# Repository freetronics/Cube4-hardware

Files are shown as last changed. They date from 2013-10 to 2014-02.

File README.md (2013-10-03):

Freetronics Cube
===========================
Copyright 2010-2013 Freetronics Pty Ltd  
Freetronics site:  www.freetronics.com  
Freetronics email: info@freetronics.com  

The Cube is a USB powered, smart RGB LED Cube kit, with a serial command
interface for direct control and learning, an open source driver library
and an on-board Arduino compatible MCU running the whole show!

The Cube was designed using the open source KiCad schematic and pcb
design package: http://www.kicad-pcb.org

The schematic pages have been carefully laid out to make it easy to follow and
learn about a larger microcontroller based project design in operation.

Features:

 * Power and control by USB commands straight from your computer (Windows, Mac or Linux)
 * Expansion port connector for sensors, joysticks, game and interface add ons
 * Onboard ATmega32u4 MCU (Arduino Leonardo compatible)
 * USB interface for uploading new sketches and sending serial commands
 * Arduino driver library with example programs and animations at:
   https://github.com/freetronics/Cube4
 * Includes ZigBee/XBee headers so you can add a wireless module (not included)
 * Prototyping area with I2C, power and spare pins next to it

More information is available on our product page at:

  http://www.freetronics.com/cube

This project is made up of 3 schematic and pcb project folders.
Each folder within this repository includes a handy copy of the
schematic in PDF format and image(s) of the main pcb.

INSTALLATION
------------
The design is saved as a KiCad project. KiCad PCB design software is
available from www.kicad-pcb.org free and open-source. To use
this project download it and place the directories containing these files
into the a folder on your computer. Then open KiCad and navigate to the
*.pro (project) file for each section.

DISTRIBUTION
------------
The specific terms of distribution of this project are governed by the
license referenced below.

LICENSE
-------
Licensed under the TAPR Open Hardware License (www.tapr.org/OHL).
The "license" folder within this repository also contains a copy of
this license in plain text format.

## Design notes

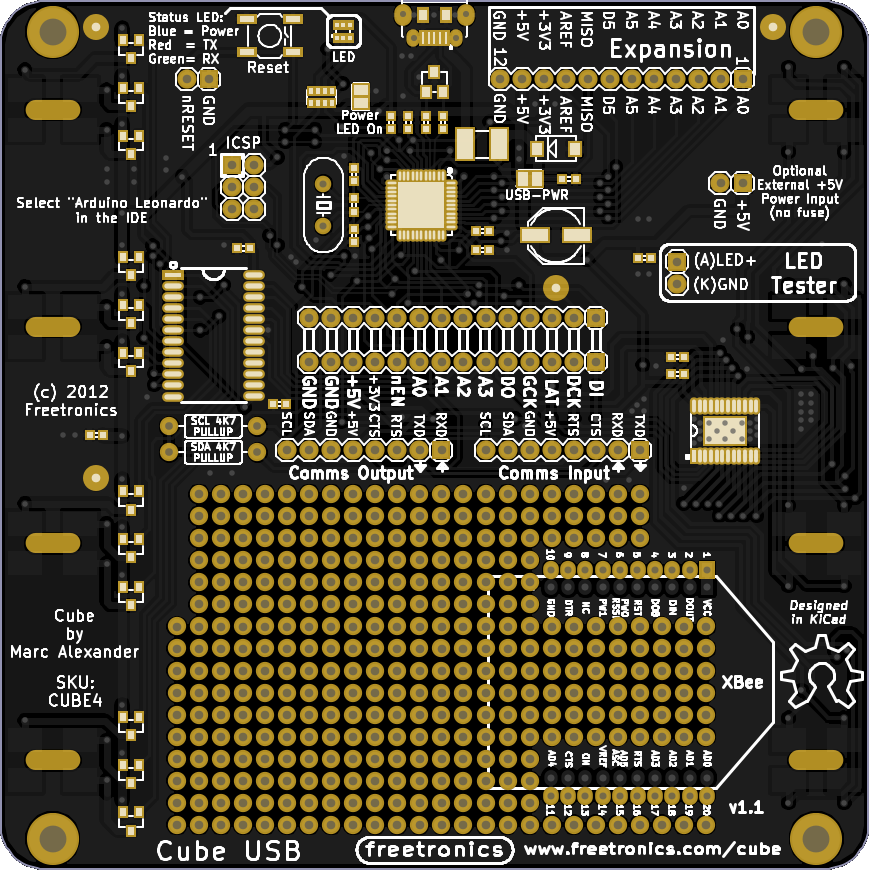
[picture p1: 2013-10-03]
cube4/cube4-top-black.png

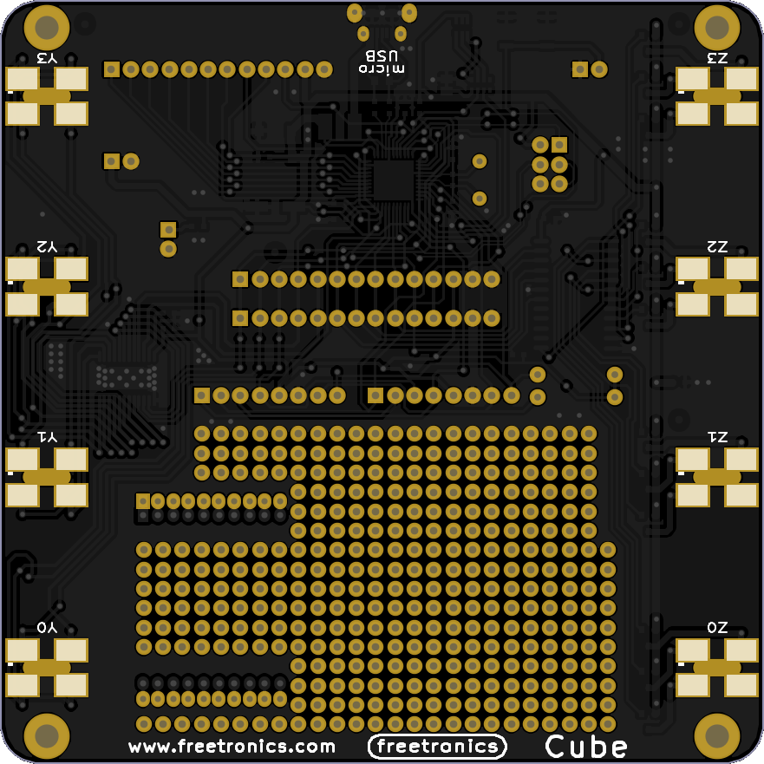
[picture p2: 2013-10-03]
cube4/cube4-bottom-black.png

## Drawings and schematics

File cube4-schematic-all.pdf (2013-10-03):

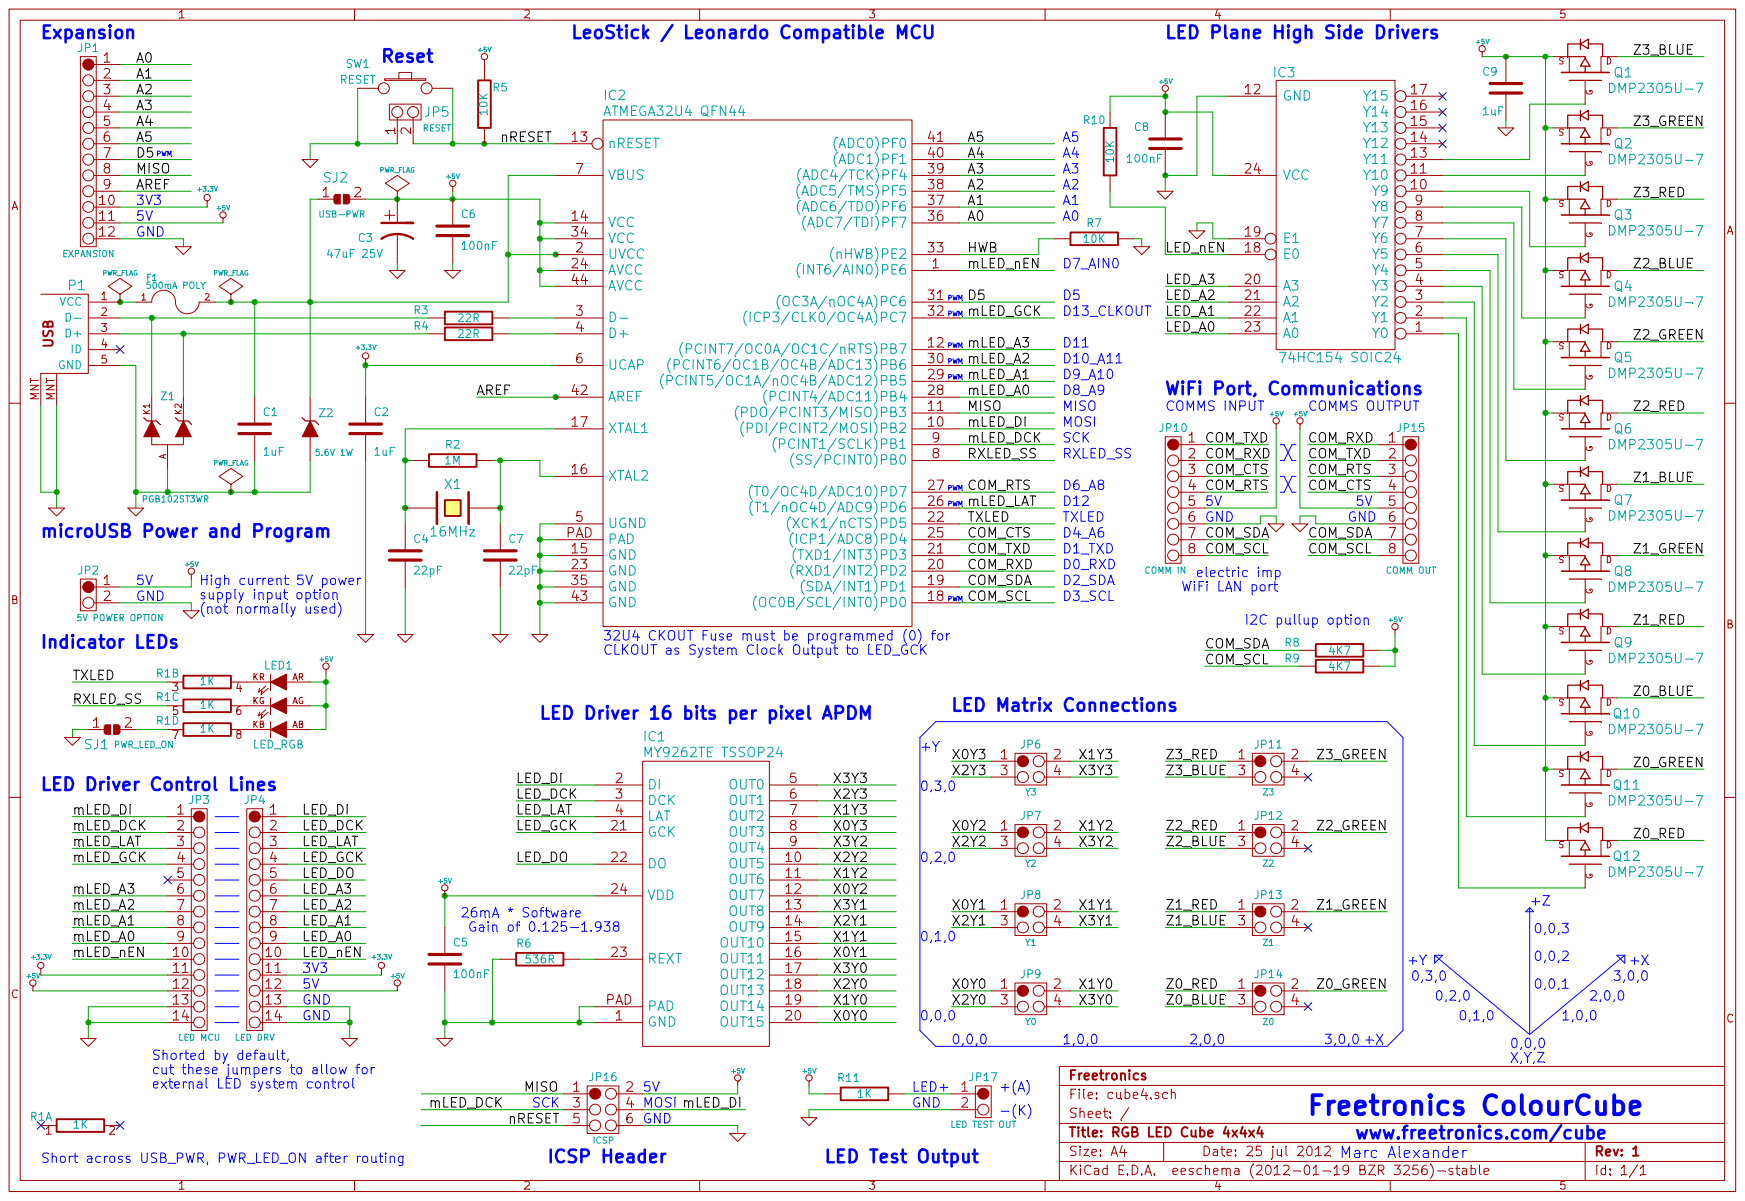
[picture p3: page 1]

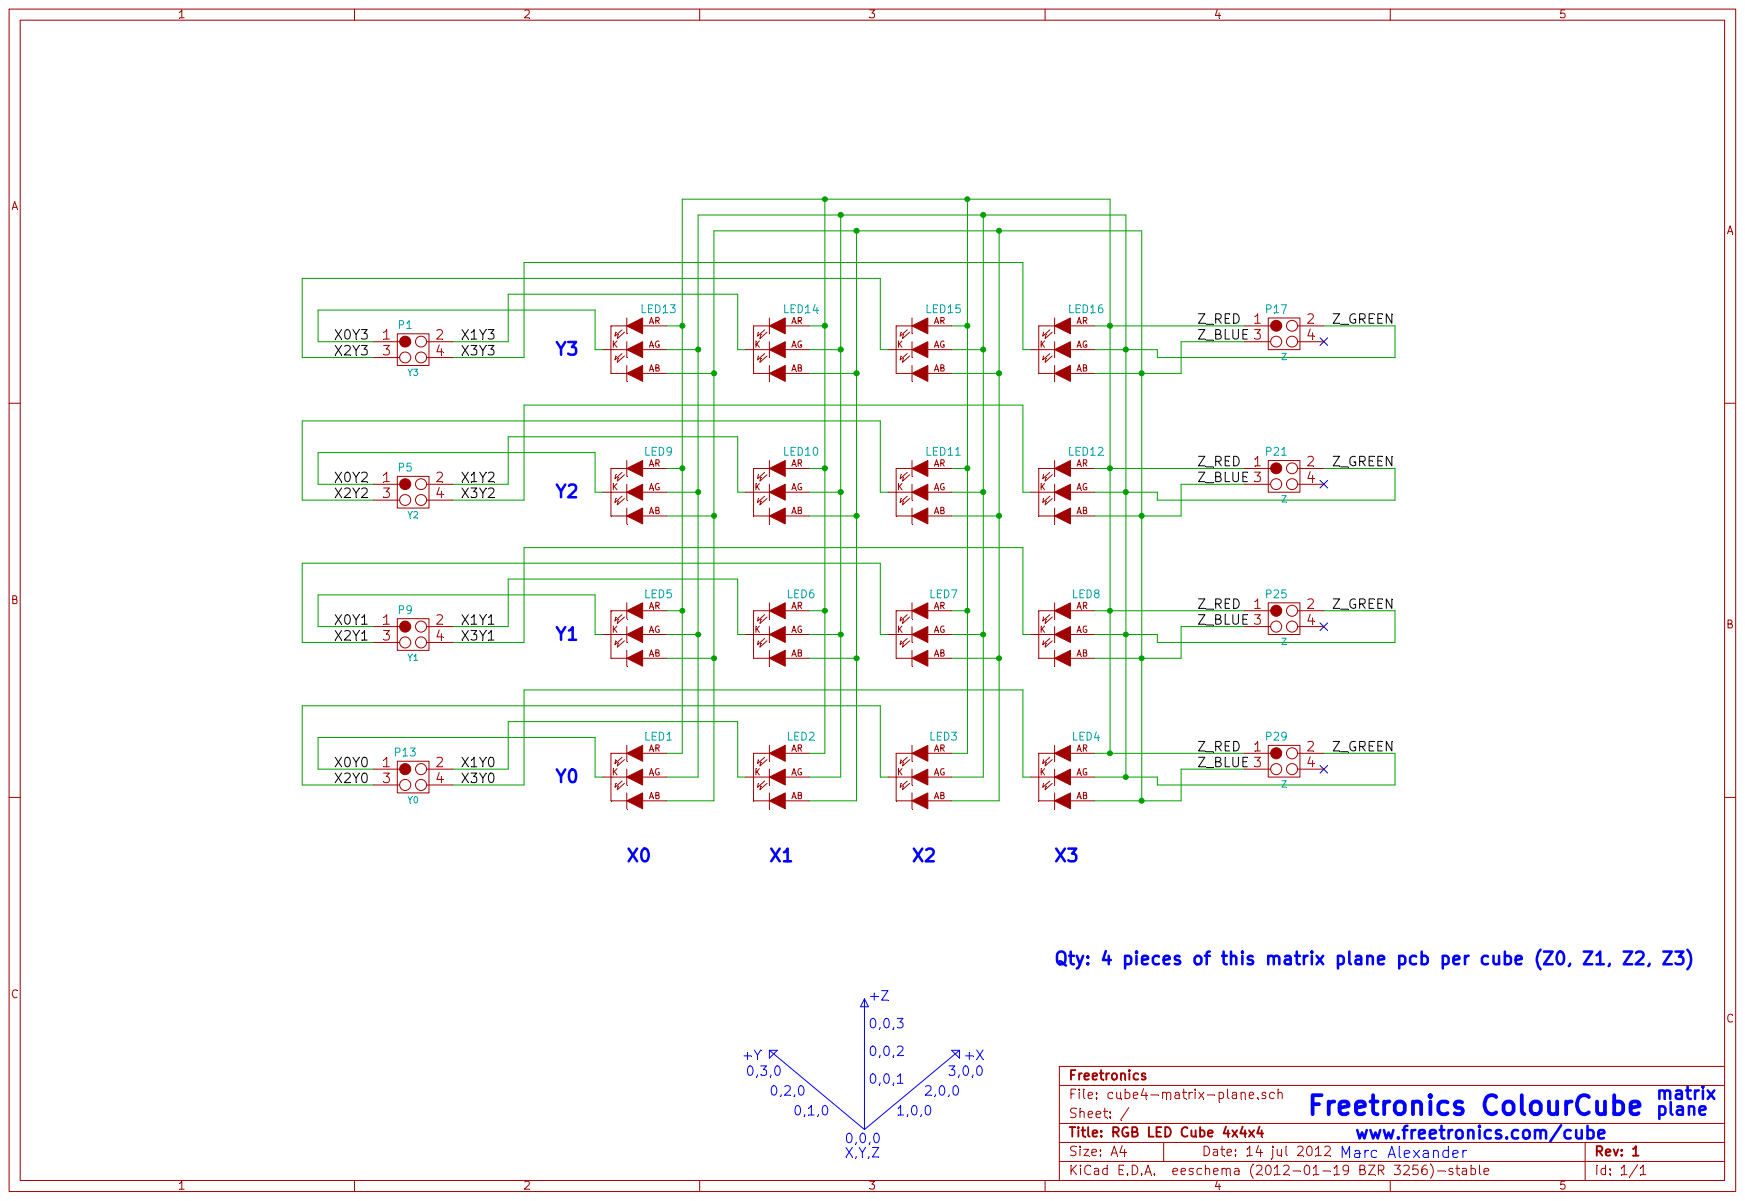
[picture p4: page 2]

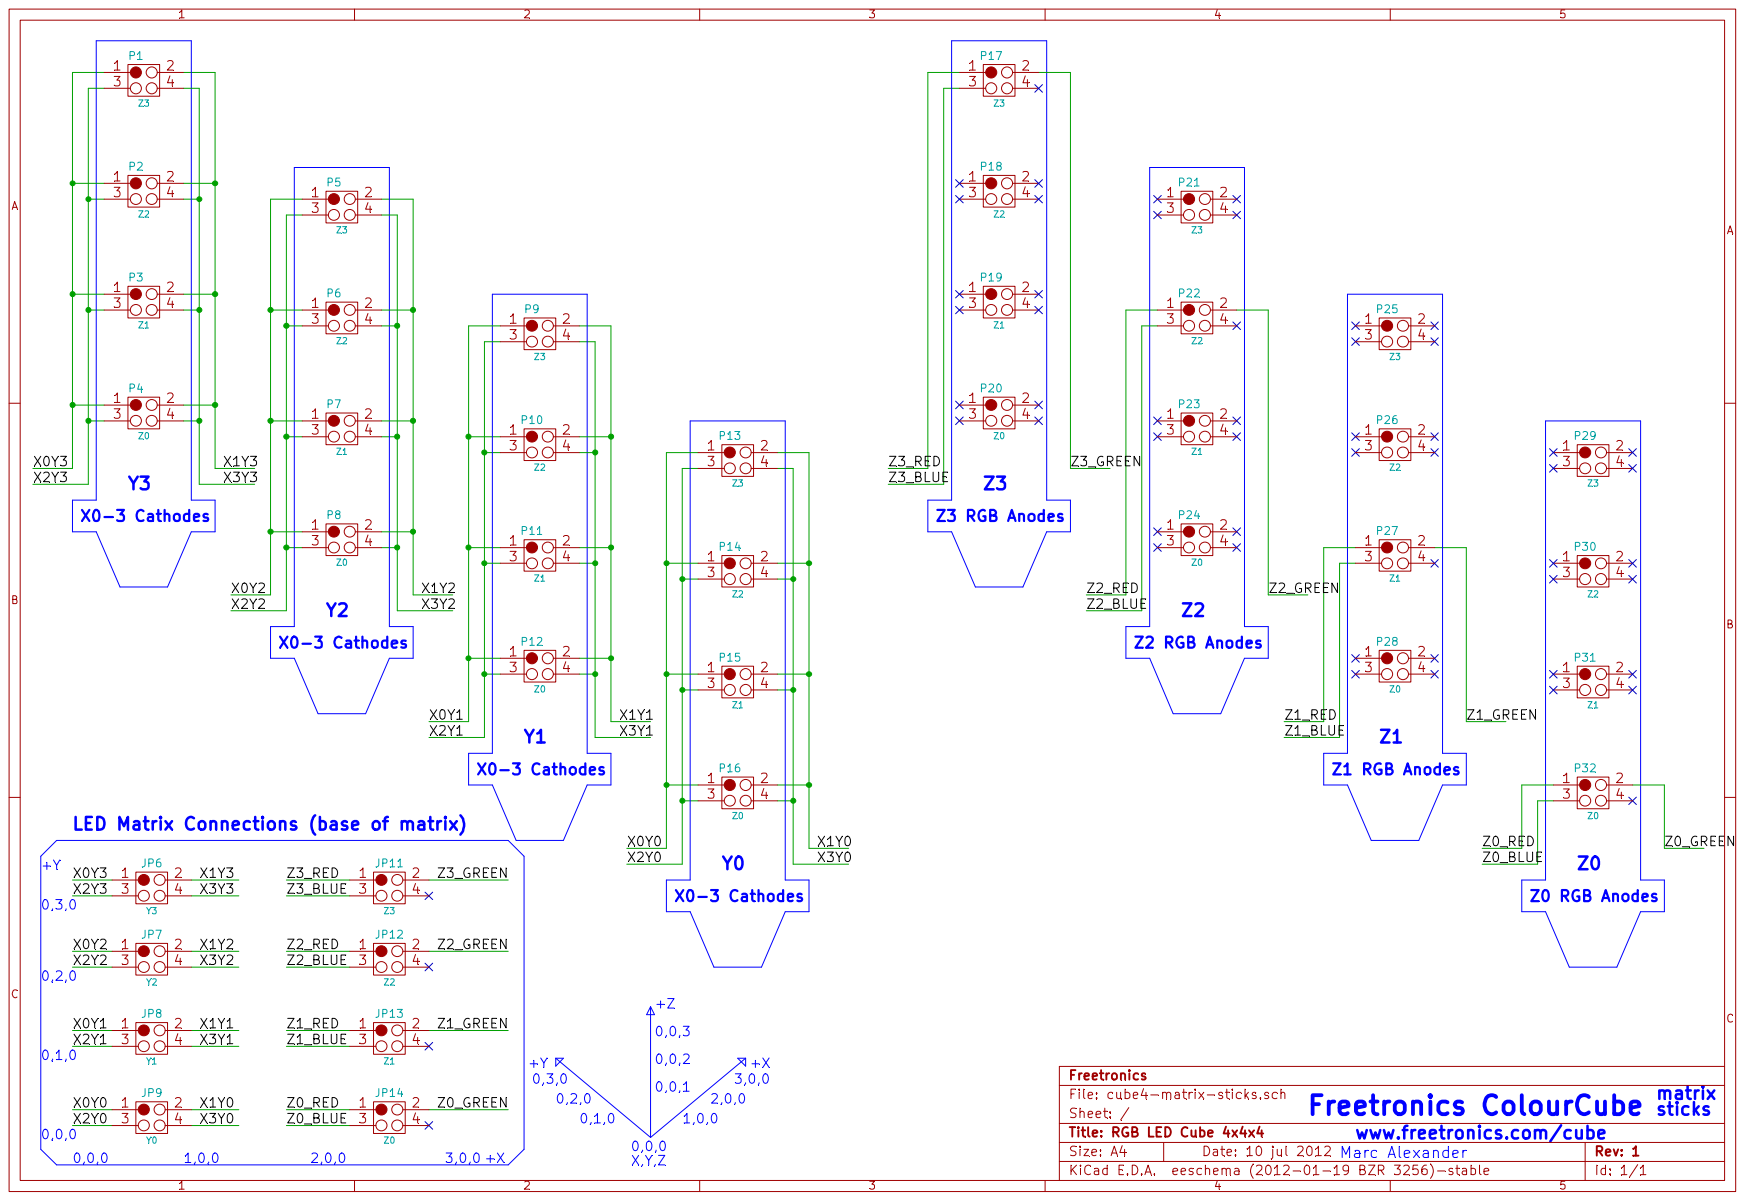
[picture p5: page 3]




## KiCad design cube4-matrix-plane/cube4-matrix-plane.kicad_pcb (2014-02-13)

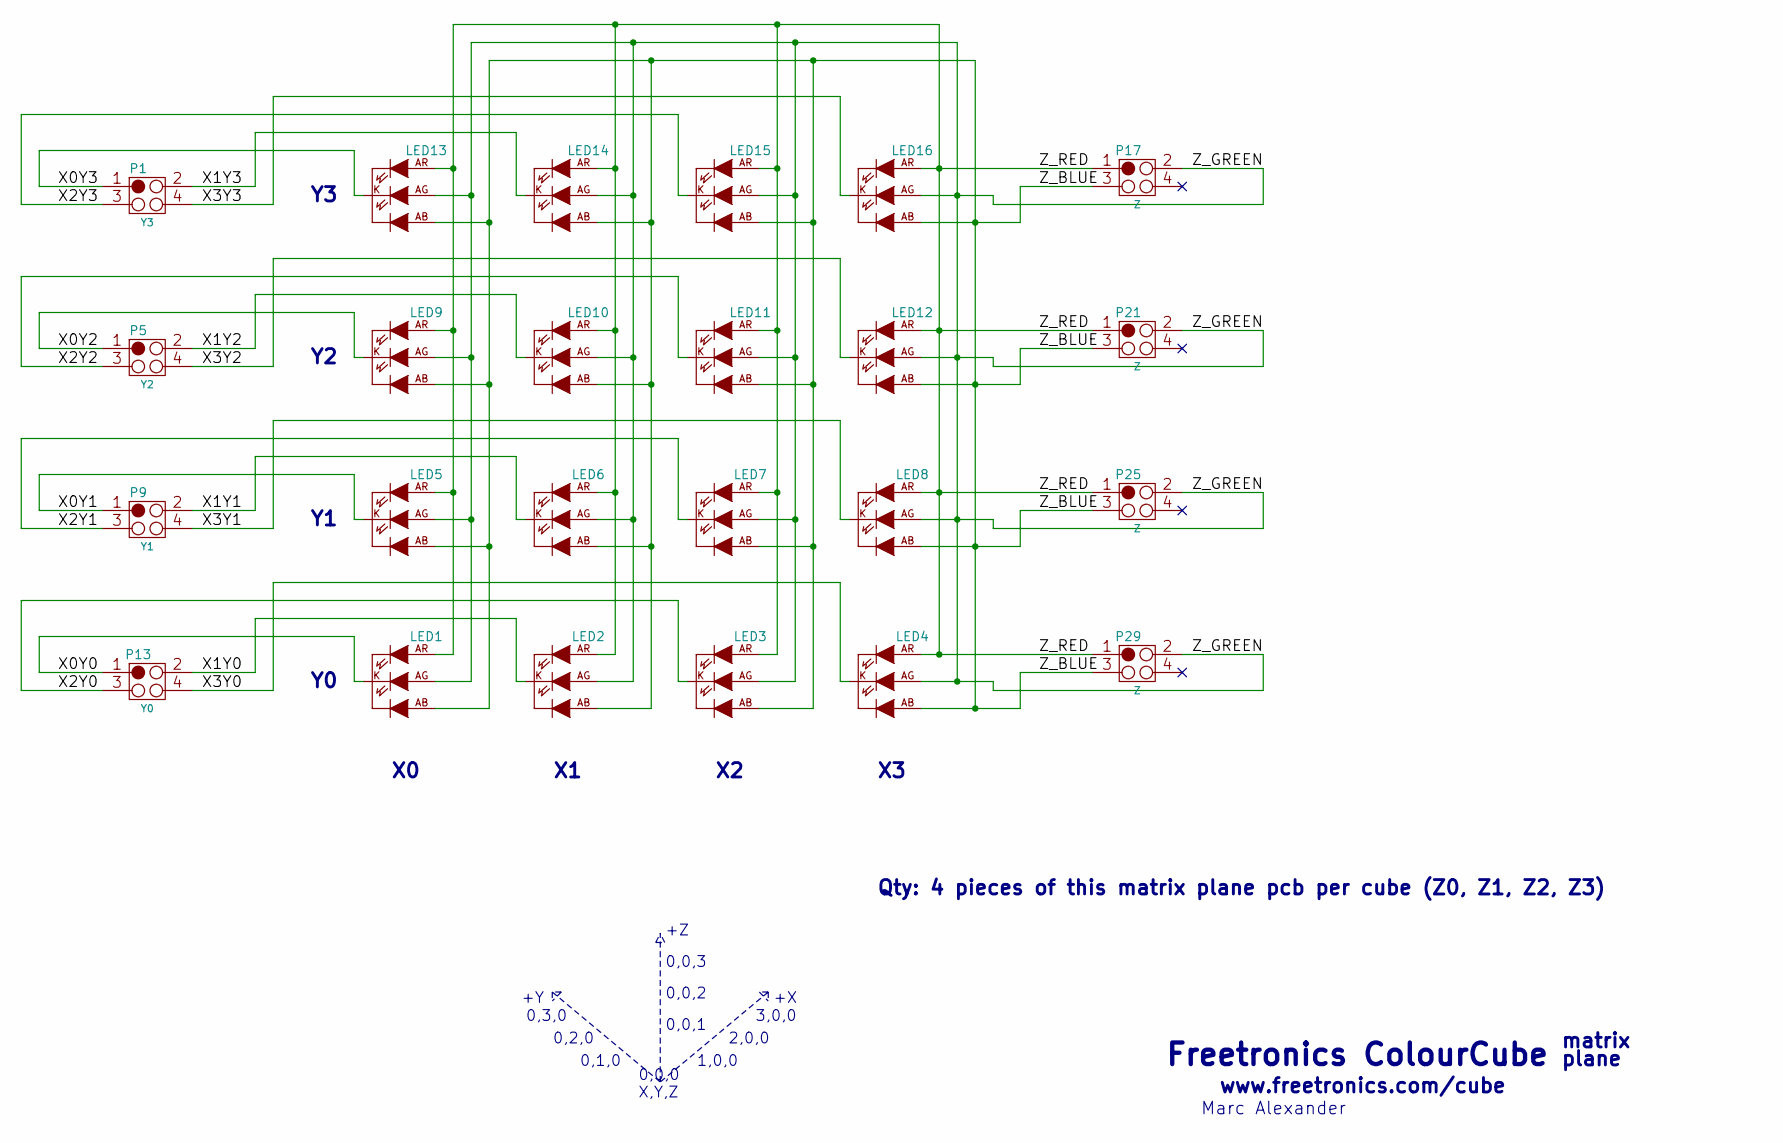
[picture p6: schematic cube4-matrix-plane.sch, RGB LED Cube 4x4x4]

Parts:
LED1, LED2, LED3, LED4, LED5, LED6, LED7, LED8, LED9, LED10, LED11, LED12, LED13, LED14, LED15, LED16: LED_RGB_COM_K; LED_RGB_8MM_COM_K
P1: Y3; LED_MATRIX_PLANE_4PAD
P5: Y2; LED_MATRIX_PLANE_4PAD
P9: Y1; LED_MATRIX_PLANE_4PAD
P13: Y0; LED_MATRIX_PLANE_4PAD
P17, P21, P25, P29: Z; LED_MATRIX_PLANE_4PAD

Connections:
/X0Y0: LED1.K, P13.1
/X0Y1: LED5.K, P9.1
/X0Y2: LED9.K, P5.1
/X0Y3: LED13.K, P1.1
/X1Y0: LED2.K, P13.2
/X1Y1: LED6.K, P9.2
/X1Y2: LED10.K, P5.2
/X1Y3: LED14.K, P1.2
/X2Y0: LED3.K, P13.3
/X2Y1: LED7.K, P9.3
/X2Y2: LED11.K, P5.3
/X2Y3: LED15.K, P1.3
/X3Y0: LED4.K, P13.4
/X3Y1: LED8.K, P9.4
/X3Y2: LED12.K, P5.4
/X3Y3: LED16.K, P1.4
/Z_BLUE: LED1.AB, LED2.AB, LED3.AB, LED4.AB, LED5.AB, LED6.AB, LED7.AB, LED8.AB, LED9.AB, LED10.AB, LED11.AB, LED12.AB, LED13.AB, LED14.AB, LED15.AB, LED16.AB, P17.3, P21.3, P25.3, P29.3
/Z_GREEN: LED1.AG, LED2.AG, LED3.AG, LED4.AG, LED5.AG, LED6.AG, LED7.AG, LED8.AG, LED9.AG, LED10.AG, LED11.AG, LED12.AG, LED13.AG, LED14.AG, LED15.AG, LED16.AG, P17.2, P21.2, P25.2, P29.2
/Z_RED: LED1.AR, LED2.AR, LED3.AR, LED4.AR, LED5.AR, LED6.AR, LED7.AR, LED8.AR, LED9.AR, LED10.AR, LED11.AR, LED12.AR, LED13.AR, LED14.AR, LED15.AR, LED16.AR, P17.1, P21.1, P25.1, P29.1

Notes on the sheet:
Qty: 4 pieces of this matrix plane pcb per cube (Z0, Z1, Z2, Z3)
plane
matrix
Marc Alexander
www.freetronics.com/cube
Freetronics ColourCube
0,0,3
0,0,2
0,0,1
0,3,0
0,2,0
0,1,0
3,0,0
2,0,0
1,0,0
0,0,0 X,Y,Z

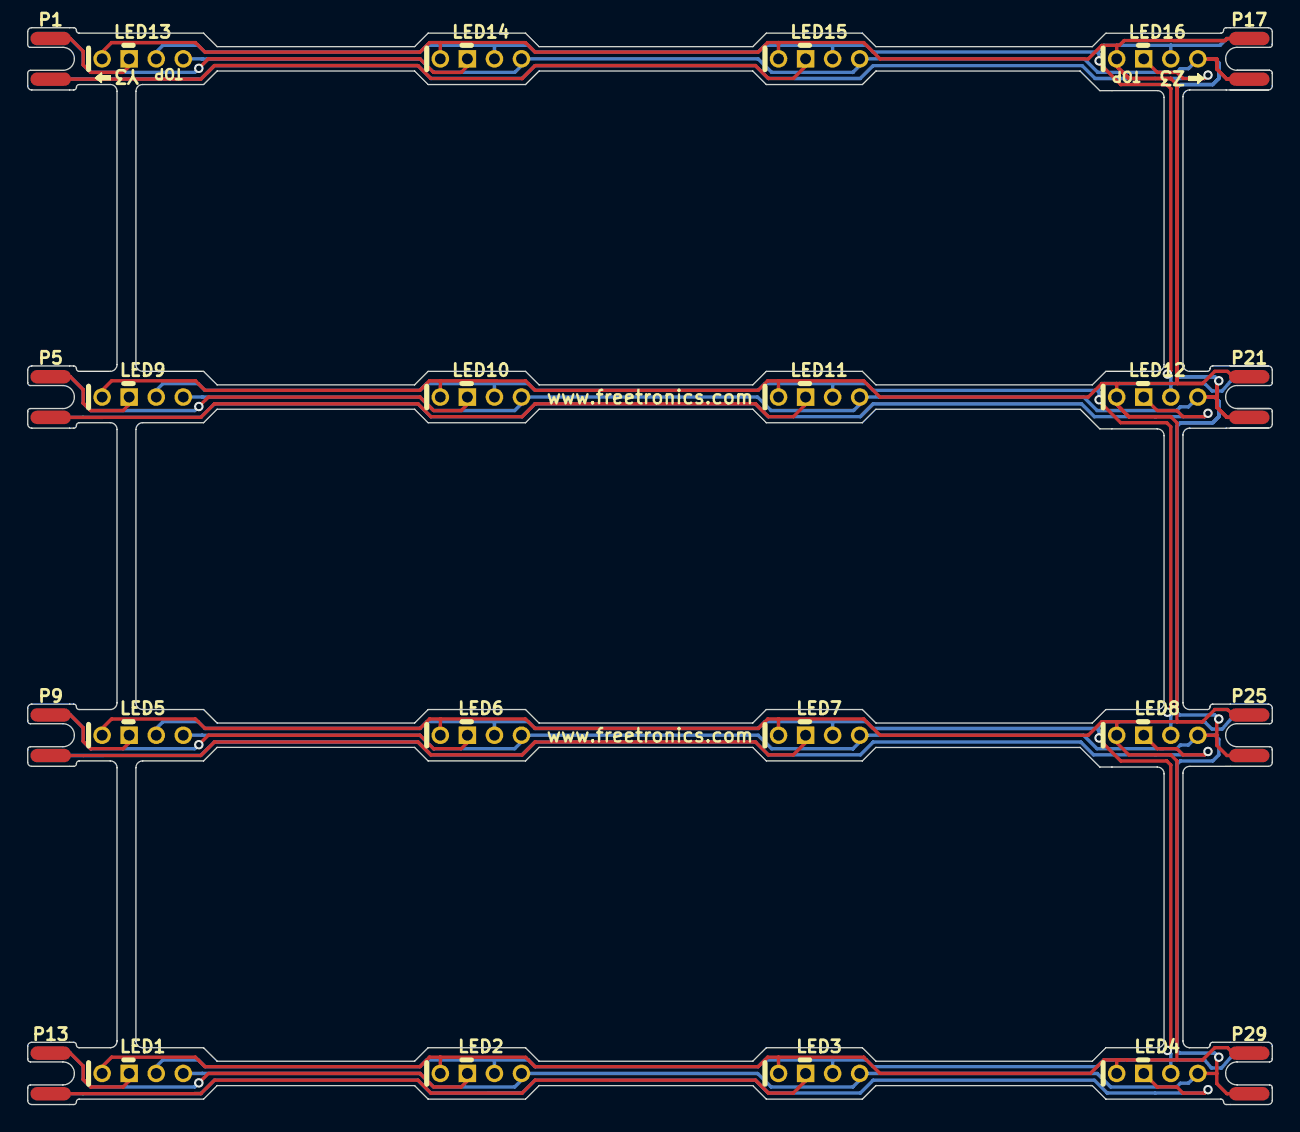
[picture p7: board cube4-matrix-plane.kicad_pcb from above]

Board: 2 copper layers, 92.0 x 79.6 mm, 24 parts (0 on the bottom side), 19 nets.

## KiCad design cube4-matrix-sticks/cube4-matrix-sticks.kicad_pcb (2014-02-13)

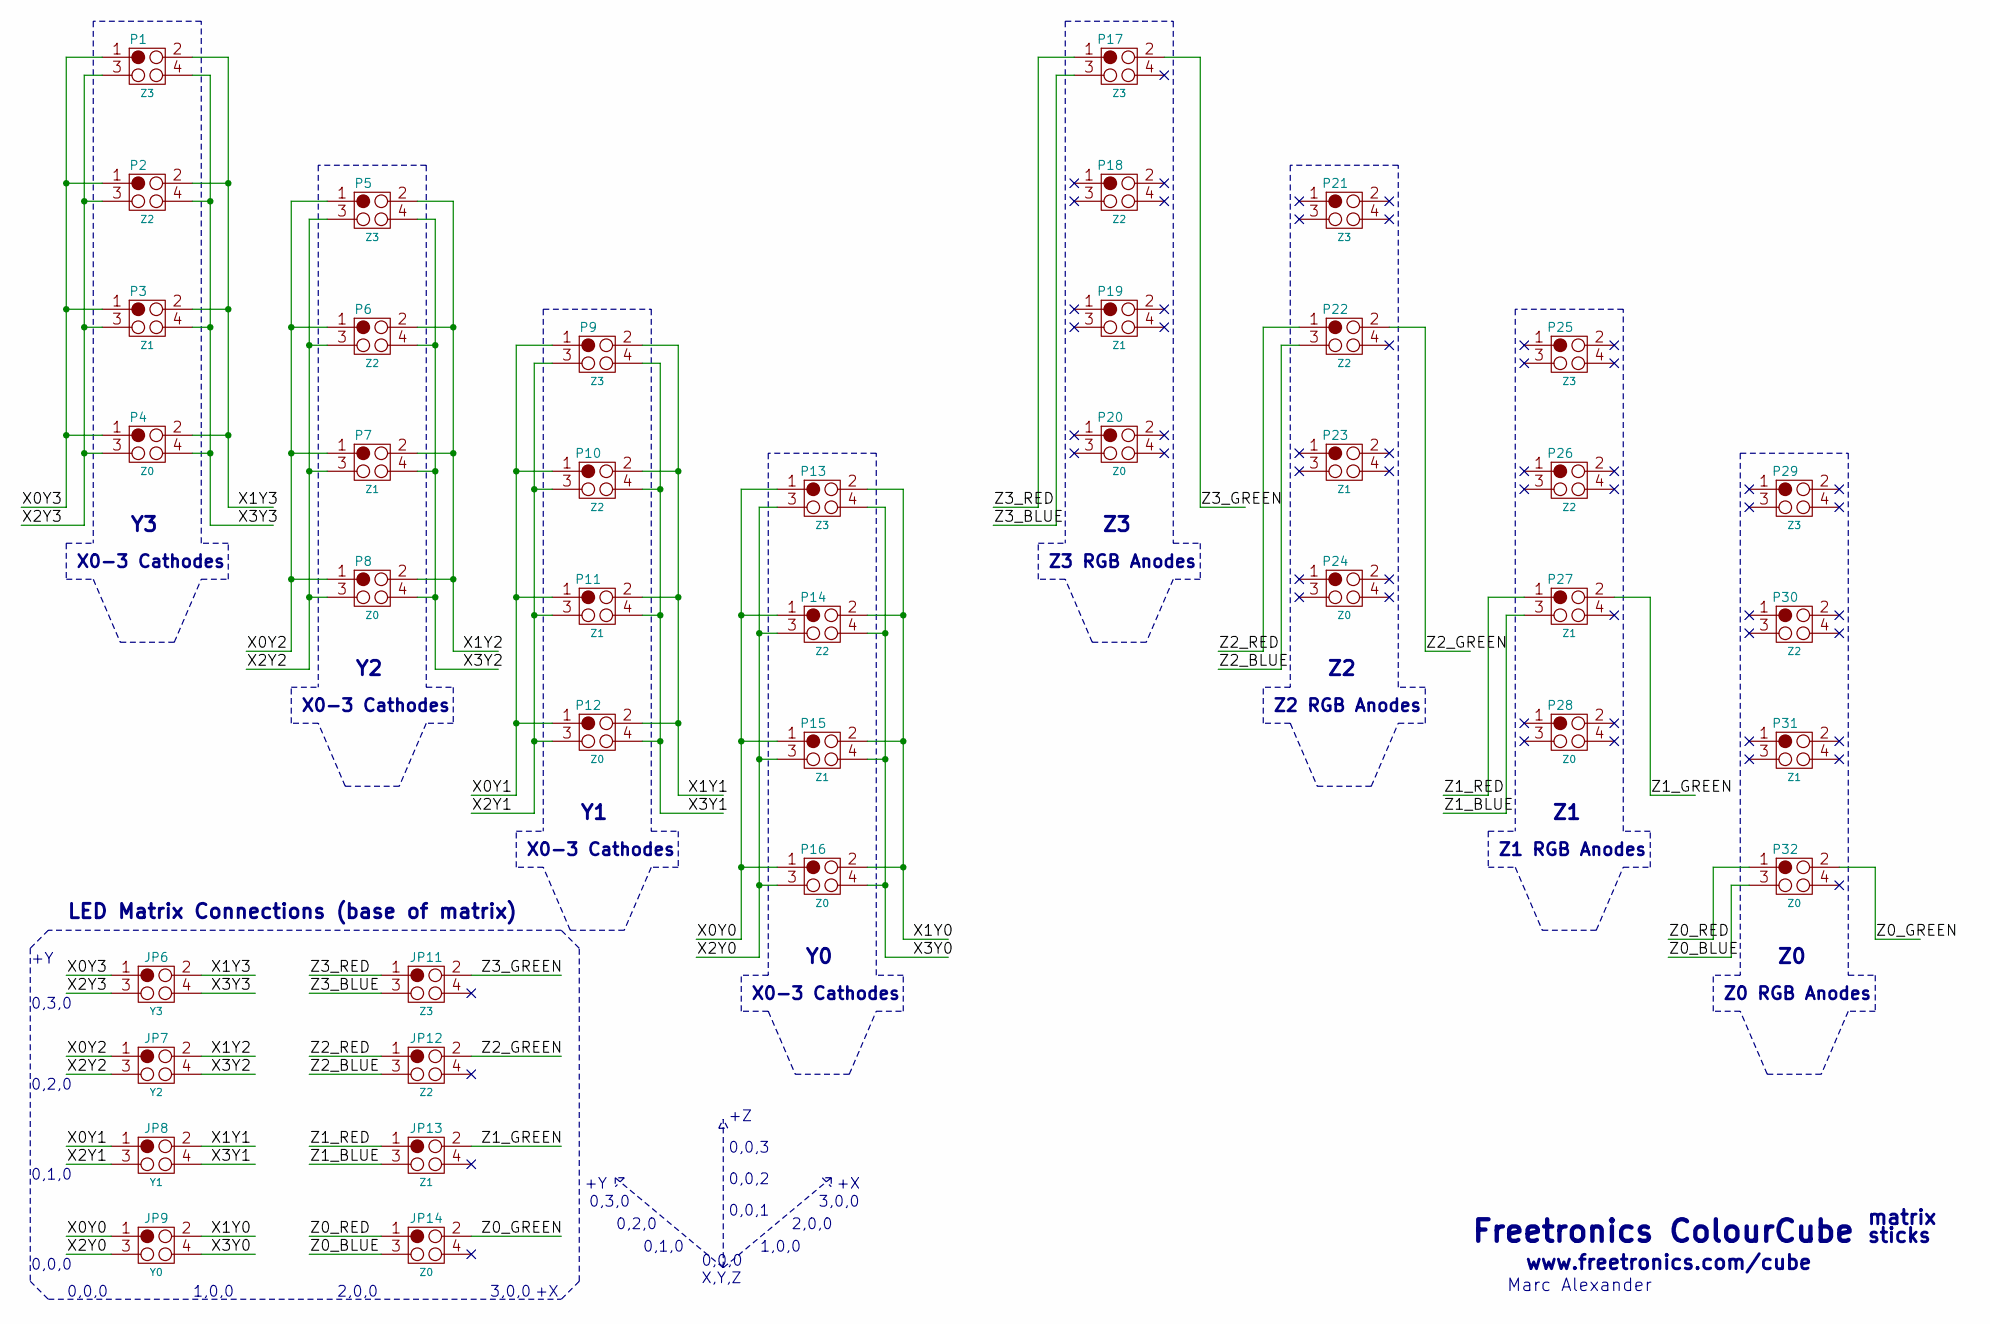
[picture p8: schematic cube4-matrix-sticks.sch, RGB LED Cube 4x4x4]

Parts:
JP6: Y3; LED_STICK_BASE_4PAD
JP7: Y2; LED_STICK_BASE_4PAD
JP8: Y1; LED_STICK_BASE_4PAD
JP9: Y0; LED_STICK_BASE_4PAD
JP11: Z3; LED_STICK_BASE_4PAD
JP12: Z2; LED_STICK_BASE_4PAD
JP13: Z1; LED_STICK_BASE_4PAD
JP14: Z0; LED_STICK_BASE_4PAD
P1, P5, P9, P13, P17, P21, P25, P29: Z3; LED_MATRIX_VERTICAL_4PAD
P2, P6, P10, P14, P18, P22, P26, P30: Z2; LED_MATRIX_VERTICAL_4PAD
P3, P7, P11, P15, P19, P23, P27, P31: Z1; LED_MATRIX_VERTICAL_4PAD
P4, P8, P12, P16, P20, P24, P28, P32: Z0; LED_MATRIX_VERTICAL_4PAD

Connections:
/X0Y0: JP9.1, P13.1, P14.1, P15.1, P16.1
/X0Y1: JP8.1, P9.1, P10.1, P11.1, P12.1
/X0Y2: JP7.1, P5.1, P6.1, P7.1, P8.1
/X0Y3: JP6.1, P1.1, P2.1, P3.1, P4.1
/X1Y0: JP9.2, P13.2, P14.2, P15.2, P16.2
/X1Y1: JP8.2, P9.2, P10.2, P11.2, P12.2
/X1Y2: JP7.2, P5.2, P6.2, P7.2, P8.2
/X1Y3: JP6.2, P1.2, P2.2, P3.2, P4.2
/X2Y0: JP9.3, P13.3, P14.3, P15.3, P16.3
/X2Y1: JP8.3, P9.3, P10.3, P11.3, P12.3
/X2Y2: JP7.3, P5.3, P6.3, P7.3, P8.3
/X2Y3: JP6.3, P1.3, P2.3, P3.3, P4.3
/X3Y0: JP9.4, P13.4, P14.4, P15.4, P16.4
/X3Y1: JP8.4, P9.4, P10.4, P11.4, P12.4
/X3Y2: JP7.4, P5.4, P6.4, P7.4, P8.4
/X3Y3: JP6.4, P1.4, P2.4, P3.4, P4.4
/Z0_BLUE: JP14.3, P32.3
/Z0_GREEN: JP14.2, P32.2
/Z0_RED: JP14.1, P32.1
/Z1_BLUE: JP13.3, P27.3
/Z1_GREEN: JP13.2, P27.2
/Z1_RED: JP13.1, P27.1
/Z2_BLUE: JP12.3, P22.3
/Z2_GREEN: JP12.2, P22.2
/Z2_RED: JP12.1, P22.1
/Z3_BLUE: JP11.3, P17.3
/Z3_GREEN: JP11.2, P17.2
/Z3_RED: JP11.1, P17.1

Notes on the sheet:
sticks
Z3 RGB Anodes
Z2 RGB Anodes
Z1 RGB Anodes
Z0 RGB Anodes
X0-3 Cathodes
matrix
Marc Alexander
www.freetronics.com/cube
Freetronics ColourCube
LED Matrix Connections (base of matrix)
0,0,0
0,3,0
0,2,0
0,1,0
3,0,0
2,0,0
1,0,0
0,0,3
0,0,2
0,0,1
0,0,0 X,Y,Z

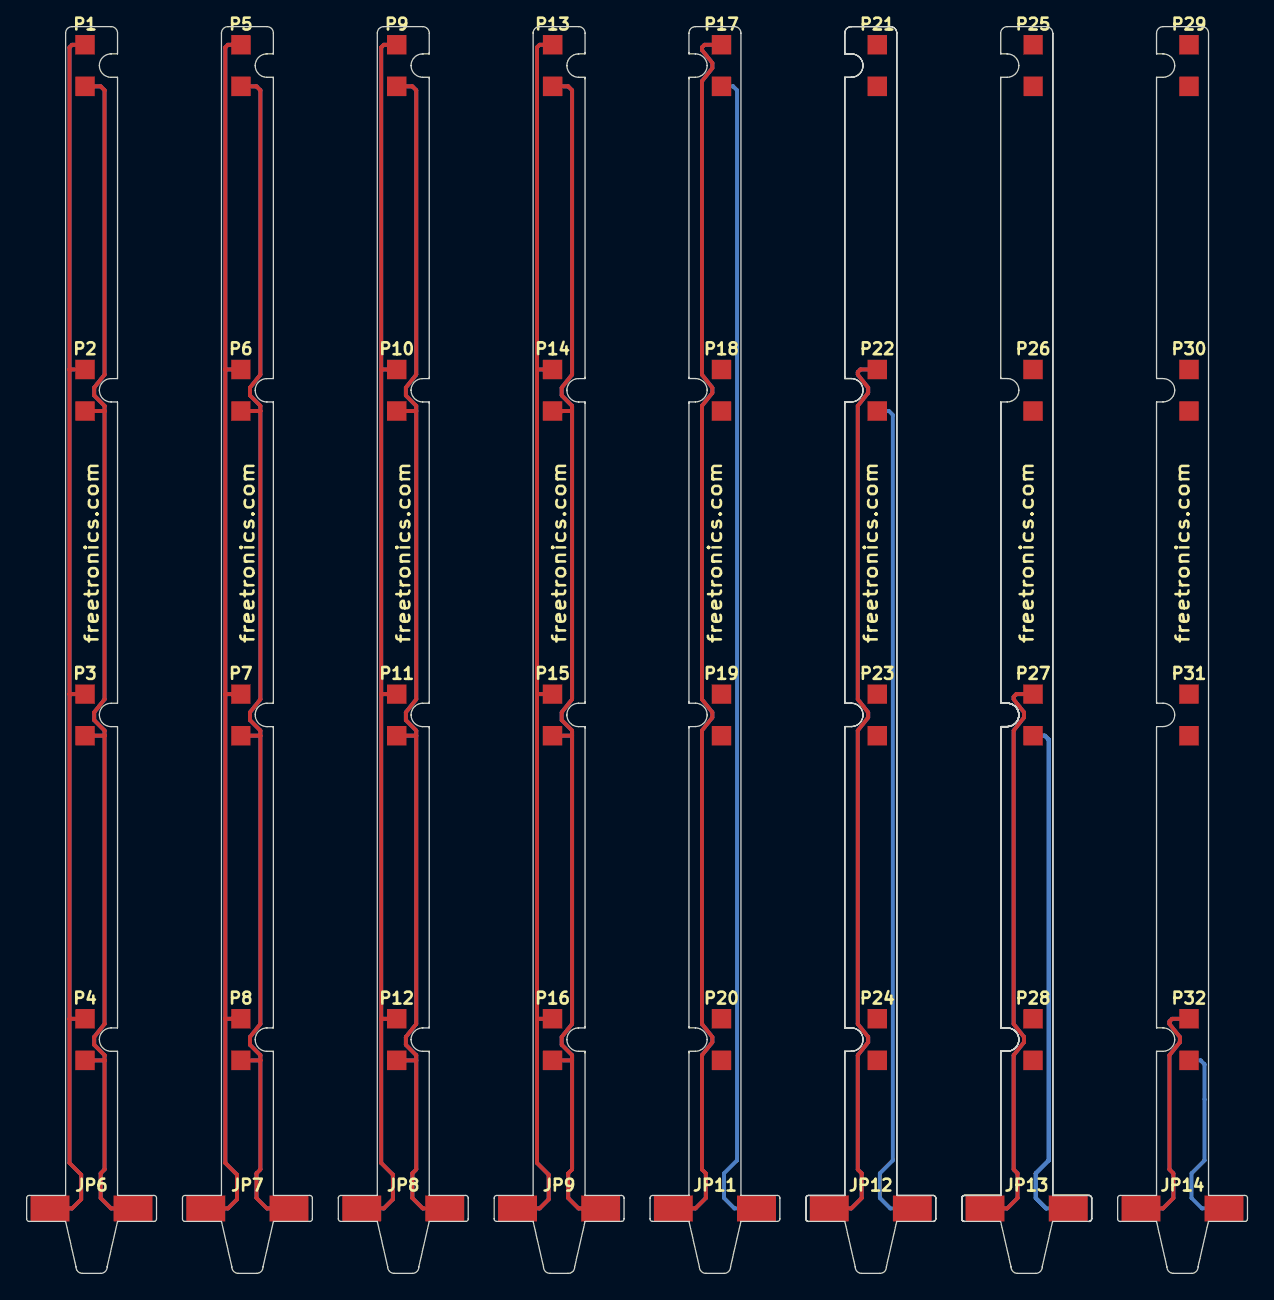
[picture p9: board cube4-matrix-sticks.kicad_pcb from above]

Board: 2 copper layers, 94.0 x 96.0 mm, 40 parts (0 on the bottom side), 28 nets.

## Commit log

2013-10-03 Cube4 release - July 2012
    [cube4-matrix-plane.brd, cube4-matrix-plane.sch, cube4-matrix-sticks.brd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]
2014-02-13 Update to Kicad 2013-July, add library as git submodule, add schematic cache files
    [cube4-matrix-plane.brd, cube4-matrix-plane.kicad_pcb, cube4-matrix-plane.sch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]

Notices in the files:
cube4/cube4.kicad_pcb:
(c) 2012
